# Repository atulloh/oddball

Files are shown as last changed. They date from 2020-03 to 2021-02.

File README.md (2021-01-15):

# Oddball Keyboard

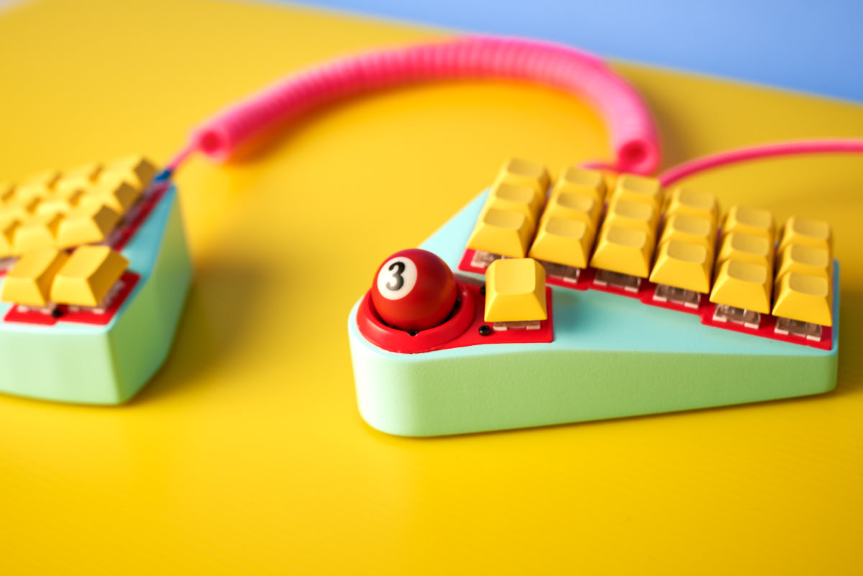
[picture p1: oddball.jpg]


The Oddball is a split mechanical keyboard with an integrated trackball. While drawing inspiration from things like the [Jian](https://github.com/KGOH/Jian-Info) and the [Dactyl Manuform](https://github.com/abstracthat/dactyl-manuform), it is instead designed with a switch plate and PCB to give it durability, replicability, and a more utilitarian look. It has a relatively minimal key layout, typically with 39 keys in total. The PCB is reversible so it can be built with 0, 1 or theoretically 2 trackballs. Due to the height and angle of the optical sensor, and as an ergonomic bonus, it requires a tented case.

- all files (cases/plates/PCBs/etc) are under [output/](https://github.com/atulloh/oddball/tree/master/output)
- all OpenSCAD files used for the 3D parts are under [src](https://github.com/atulloh/oddball/tree/master/src)

## [View the docs](https://atulloh.github.io/oddball)

## Features
- split design
- 39 keys
- trackball
- click, click + drag, scroll
- dynamic CPI (trackball cursor speed)
- columnar staggered keys
- tented case
- angled thumb clusters
- QMK firmware

Feel free to [reach out](https://atulloh.github.io/oddball/about-me) if you have any questions.

# License

MIT License

Copyright (c) 2021 Alexander Tulloh

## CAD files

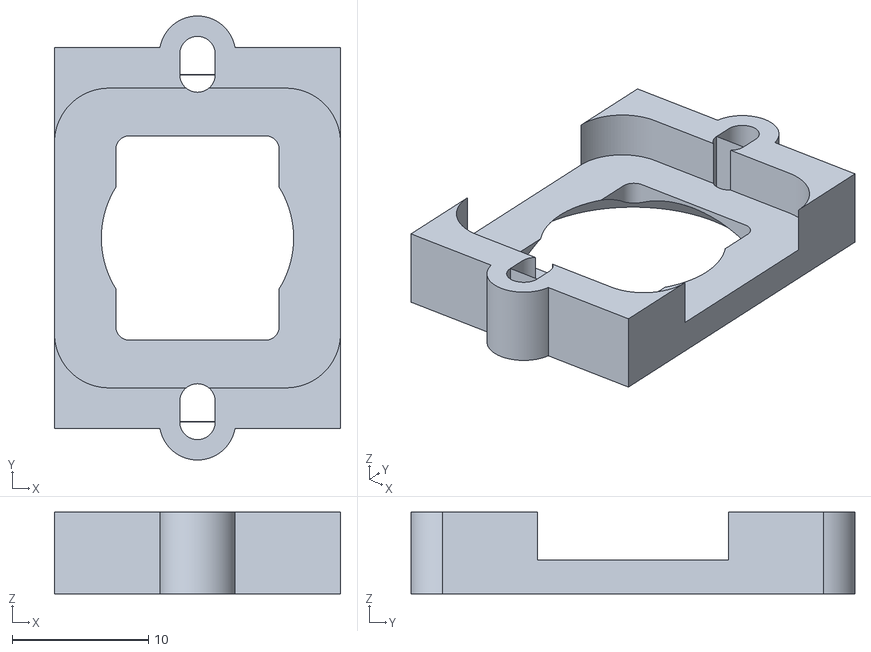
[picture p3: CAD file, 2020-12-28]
output/case/v2.0/pmwCover.stl
21.0 x 32.6 x 6.00

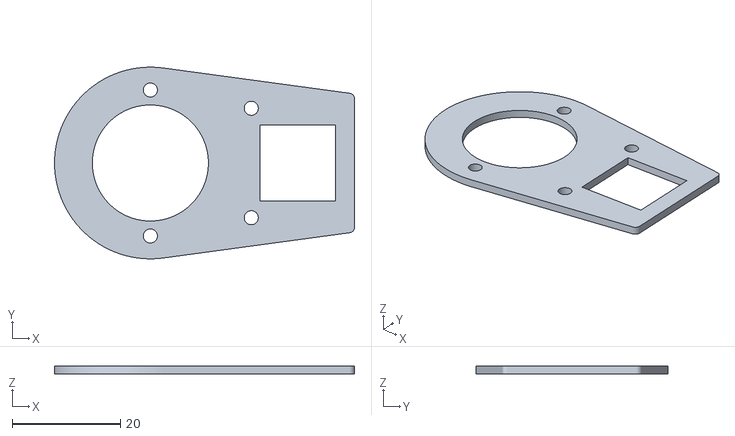
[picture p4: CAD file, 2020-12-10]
output/plates/v2.0/rightThumbPlate.stl
55.5 x 35.5 x 1.50

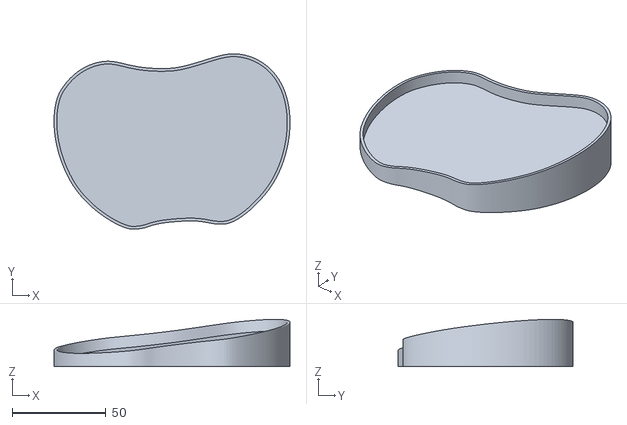
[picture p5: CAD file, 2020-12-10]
output/wristRests/leftWristRest.stl
125.7 x 93.4 x 25.2

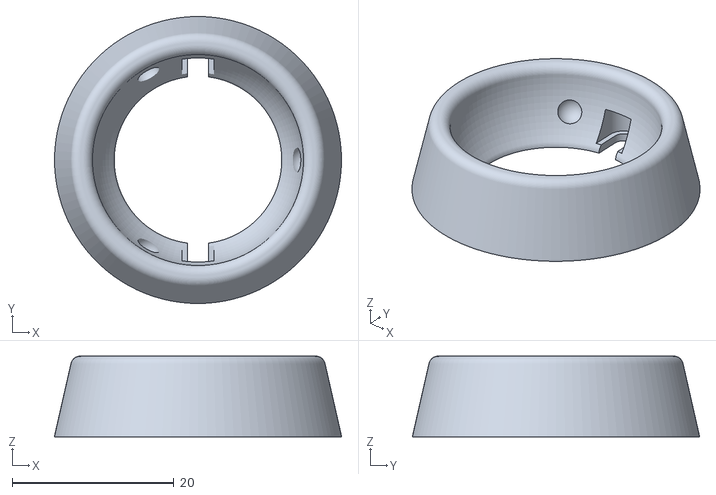
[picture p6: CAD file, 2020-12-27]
output/case/v2.0/bearingMount.stl
35.5 x 35.5 x 10.00

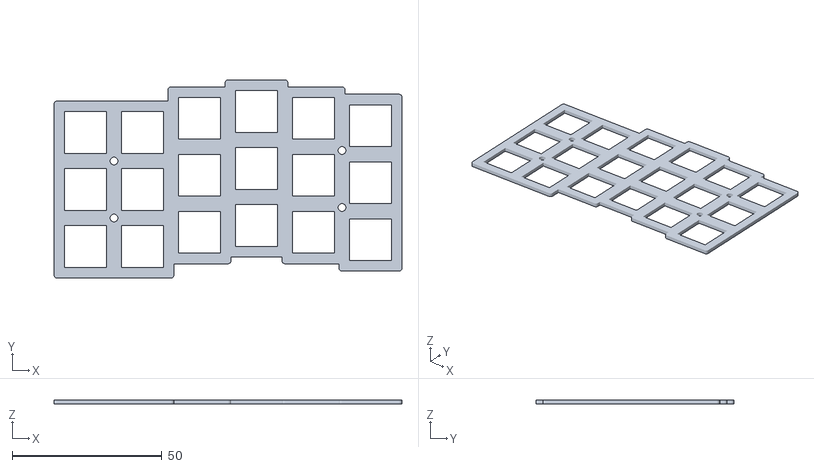
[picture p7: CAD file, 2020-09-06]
output/plates/v2.0/leftPlate.stl
116.3 x 66.2 x 1.50

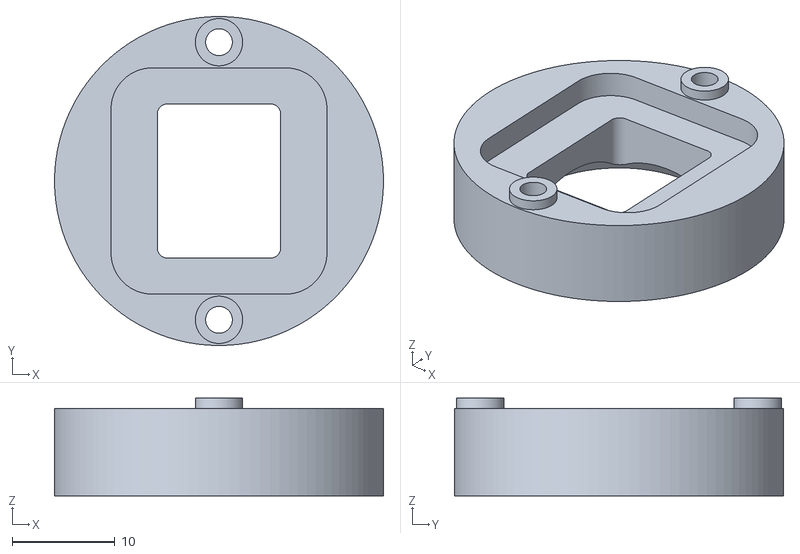
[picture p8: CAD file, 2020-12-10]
output/case/v2.0/adnsCover.stl
32.0 x 32.0 x 9.50

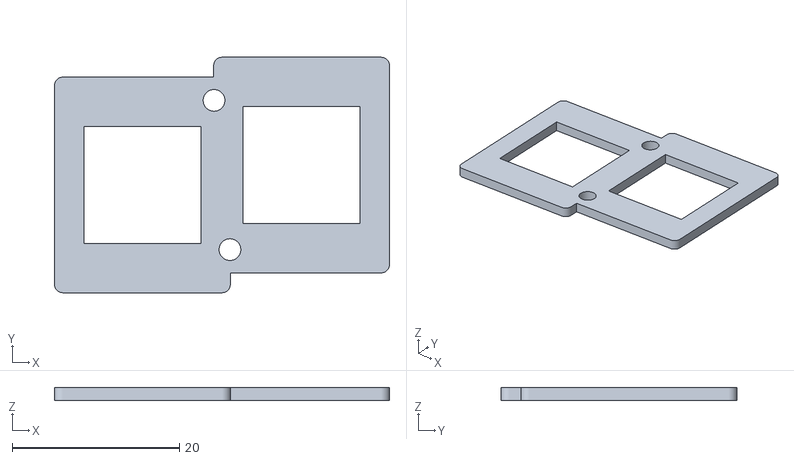
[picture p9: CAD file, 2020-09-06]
output/plates/v2.0/leftThumbPlate.stl
40.1 x 28.2 x 1.50

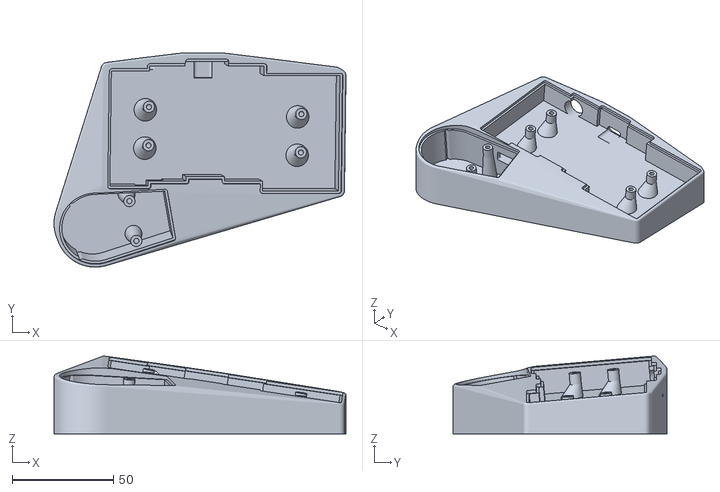
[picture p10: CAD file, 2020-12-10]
output/case/v2.0/rightCase.stl
144.3 x 105.9 x 38.4

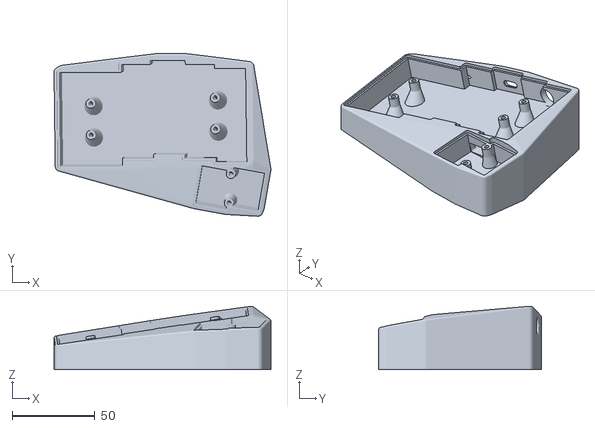
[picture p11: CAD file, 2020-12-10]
output/case/v2.0/leftCase.stl
131.4 x 98.4 x 38.4

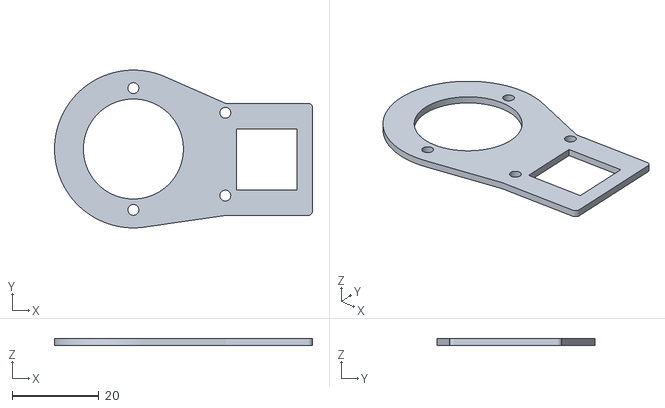
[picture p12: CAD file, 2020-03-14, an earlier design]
output/plates/v1.0/rightThumbPlate.stl
59.3 x 36.3 x 1.50

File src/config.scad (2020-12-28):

// draw flags

DRAW_DEBUG = false;

// MX constants

1U = 19.05;
SWITCH_WIDTH = 14;

// hardware

NUT_DIAMETER = 4;
NUT_HEIGHT = 3;
NUT_TOLERENCE = 0.5;
BOLT_DIAMETER = 2.4; // M2 cleanance
BOLT_TOLERENCE = 0.1;
BOLT_TOP_DIAMETER = 3.8;
BOLT_TOP_HEIGHT = 2.5;
BOLT_LENGTH = 18;
THUMB_BOLT_LENGTH = 22;

BEARING_DIAMETER = 3.175;
BEARING_TOLERENCE = 0.05;

// plate

PLATE_THICKNESS = 1.5;
PLATE_BEZEL = 1;
PLATE_CURVE_RADIUS = 1;

// trackball

TRACKBALL_BOLT_HOLES_DIAMETER = 32;
TRACKBALL_DIAMETER = 24.9;
TRACKBALL_PLATE_CLEARANCE = 1.5;
TRACKBALL_PLATE_BEZEL = 7;
TRACKBALL_BEARING_MOUNT_CLEARANCE = 1.8;
TRACKBALL_POSITION_Z = 8.35;

// common sensor

SENSOR_CHANNEL_WIDTH = 12;
SENSOR_CHANNEL_HEIGHT = 15;
SENSOR_LENS_CLEARANCE = 2.4 - 4; // 2.4 from ADNS9800/PMW3600 data sheets, but needed a slight reduction, probably due to print tolerences
SENSOR_LENS_HEIGHT_ABOVE_BOARD = 3.5;
SENSOR_LENS_WIDTH = 21; 
SENSOR_LENS_HEIGHT = 22;
SENSOR_PCB_MOUNT_OFFSET = 13.5; // distance in X/Y from centre
SENSOR_PCB_THICKNESS = 1.5;
SENSOR_PCB_UNDERSIDE_CLEARANCE = 21.5;
SENDOR_TRACKBALL_CLEARANCE = 1;

// ADNS9800 sensor

ADNS_PCB_DIAMETER = 32;

// PMW3360 sensor

PMW_PCB_WIDTH = 21;
PMW_PCB_HEIGHT = 28;
PMW_PCB_MOUNT_OFFSET = 12;

// bearing mount

BEARING_OFFSET_Z = 3.8;
BEARING_MOUNT_TOP_CURVE_RADIUS = 1.2;
BEARING_MOUNT_TOP_X_MAX = 5;
BEARING_MOUNT_HEIGHT = 10;
BEARING_MOUNT_BOLT_TOP_CLEARANCE = 1.5;
BEARING_BOLT_CLEARANCE_Z = 1;

// PCB

MX_PCB_OFFSET = 5;
PCB_CURVE_RADIUS = 2;
PCB_PLATE_OFFSET_Z = MX_PCB_OFFSET - PLATE_THICKNESS;
PCB_THICKNESS = 1.6;
PCB_UNDERSIDE_CLEARANCE = 7;
PCB_CASE_CLEARANCE = 1;
PCB_SWITCH_OFFSET = 0;

PRO_MICRO_SIZE = [17.8, 33];
PRO_MICRO_USB_OVERHANG = 2;

MCU_PCB_OFFSET = 3.5; // socket or header height
MCU_PCB_THICKNESS = 1; // Elite C

// case

CASE_PLATE_BEZEL = 1;
CASE_PLATE_TOLERENCE = 0.25;
CASE_CURVE_RADIUS = 1;
CASE_PLATE_MOUNT_COVERAGE = 1;
CASE_BOLT_HOUSING_WIDTH = 1.5;
CASE_BOTTOM_THICKNESS = 2;
CASE_HEIGHT_ABOVE_PLATE = 0;
CASE_STANDOFF_FLANGED = true;

// case feet cutouts

FEET_DIAMETER = 8;
FEET_TOLERENCE = 1.25;
FEET_HEIGHT = 1;

// layouts in 1U space

FINGER_GRID = 
    [[0, 2], [1, 2], [2, 2.25], [3, 2.37], [4, 2.25], [5, 2.12],
     [0, 1], [1, 1], [2, 1.25], [3, 1.37], [4, 1.25], [5, 1.12],
     [0, 0], [1, 0], [2, 0.25], [3, 0.37], [4, 0.25], [5, 0.12]];

FINGER_BOLT_HOLES =
    [[1, 2], [5, 2.185],
     [1, 1], [5, 1.185]];

THUMB_GRID = [[0, 0], [1, 0.1]];

THUMB_BOLT_HOLES = 
    [[0.95, 0.925],
     [1.05, 0.175]];

THUMB_TRACKBALL_GRID = [[0, 0], [1.43, 0, "pmw" /* "adns" */ ]];

THUMB_TRACKBALL_BOLT_HOLES = 
    [[0.95, 0.925],
     [0.95, 0.075]];

FEET_POSITIONS =
    [[0.3, 2.75], [5.6, 2.85],
     [0.3, 0.3], [5.95, -1.1]];

THUMB_FEET_POSITIONS =
    [[0.3, 2.75], [5.6, 2.85],
     [0.3, 0.3], [6.45, -1.25]];

// plane rotations

HAND_ROTATION = [5, -8.5, 0];
THUMB_ROTATION = [10, -2, -10.25];
THUMB_OFFSET = [80.5, -22, 8.5];

// cutouts

USB_C_SIZE = [8.98, 9.20, 3.28];
USB_C_CUTOUT_TOLERENCE = 0.5;
USB_C_CUTOUT_OUTER_DELTA = 1.5;

TRRS_CUTOUT_SIZE = 5.5;
TRRS_CUTOUT_OUTER_DELTA = 5.5;

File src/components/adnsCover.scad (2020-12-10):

use<../modules/adnsCover.scad>;

// flip; easier to 3D print
rotate([180,0,0])
    adnsCover($fn = 100);

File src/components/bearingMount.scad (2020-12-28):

include<../config.scad>;
use<../modules/plate.scad>;
use<../modules/bearingMount.scad>;

bearingMount($fn = 100);

if(DRAW_DEBUG)
    %translate([0,0,TRACKBALL_POSITION_Z])
        sphere(d = TRACKBALL_DIAMETER);

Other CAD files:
output/plates/v1.0/leftThumbPlate.stl
output/plates/v1.0/leftPlate.stl
src/components/handPcb.scad
output/plates/v1.0/leftPlate.dxf
output/plates/v1.0/leftThumbPlate.dxf
output/plates/v1.0/rightThumbPlate.dxf
output/plates/v2.0/leftPlate.dxf
output/plates/v2.0/leftThumbPlate.dxf
output/plates/v2.0/rightThumbPlate.dxf
src/components/leftCase.scad
src/components/leftPlate.scad
src/components/leftThumbPlate.scad
src/components/pmwCover.scad
src/components/rightCase.scad
src/components/rightPlate.scad
src/components/rightThumbPlate.scad
src/components/thumbPcb.scad
src/modules/adnsCover.scad
src/modules/bearingMount.scad
src/modules/case.scad
src/modules/keycap.scad
src/modules/keys.scad
src/modules/leftCase.scad
src/modules/pcb.scad
src/modules/plate.scad
src/modules/pmwCover.scad
src/modules/rightCase.scad
src/modules/shapes.scad
src/modules/switch.scad
src/tests/leftCaseCutouts.scad
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

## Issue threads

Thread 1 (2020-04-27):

Add plate source

atulloh, 2020-04-27:

atulloh, 2020-05-04:
This is basically covered in https://github.com/atulloh/oddball/pull/4

The goal was to take out all the hacky tweaks that were happening with the initial OpenSCAD code, and pull out all parameters into a single file.

I've added the scad files and also the output STL and DXF files for the plates and bearing mount.

Closed 2020-05-04.

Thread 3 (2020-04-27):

Create build guide

atulloh, 2020-04-27:

jdayton3, 2020-04-27:
@atulloh - if you have an extra set of PCBs you'd like to sell and would like someone to help with the build guide or be a beta tester or anything like that, feel free to hit me up! You can PM me at u/knot-a-robot, respond here, or find my other contact info at my GitHub profile -> home page if you're interested. I'm super excited about this project!

atulloh, 2020-04-27:
Thanks @jdayton3 , I'll definitely need feedback on the build process; I'll keep you posted.

keyboard-magpie, 2020-10-10:
hey @atulloh just ordered some v2 pcbs; does the build guide need an update to mention these? I saw the silks changed from teensy to elite c.

atulloh, 2020-10-11:
Hey @keyboard-magpie ...

> hey @atulloh just ordered some v2 pcbs...

Wow, you're on ball! I've only just ordered some too, you might even beat me to it.

> ...does the build guide need an update to mention these? I saw the silks changed from teensy to elite c.

Yep. I never actually wrote a build guide for v1 (sorry @jdayton3 !). I'm just in the process of doing it for both v1/v2 on this work-in-progress branch: https://github.com/atulloh/oddball/tree/blog/v2. The formatting and images won't actually work correctly until it's merged into the GitHub pages branch as it's generated with Jekyll. I also probably won't merge it in until I've actually finished a build, which will be several weeks as I'm still waiting for parts to arrive.

The main changes for v2 were:
- switched to Elite C
- added support for PMW3360 (although you can still use an ADNS9800)

I'll update this issue when I get around to merging the build guide in.

keyboard-magpie, 2020-10-14:
I should ask, are there any case differences between v1 and 2?

atulloh, 2020-10-14:
Yep, slight changes, mainly to:
- make assembly easier
- make room for the PMW3360

You can see the work-in-progress files here: https://github.com/atulloh/oddball/blob/develop/v2.0/output/case/v2.0/

Hopefully I can get my printer back in the next week or two (we are under lockdown due to virus), then do some test prints, make some measurements, and get the case files finished up.

atulloh, 2020-10-14:
@keyboard-magpie nice! Like I said though, the cases are a work-in-progress; I'll need to tweak the cable cutouts. I'll probably also try to reduce the height a bit. I'll merge that `develop/v2.0` branch back into `master` when I've had a chance that every fits together okay.

Sure, discord is tullonator#6580

gorbachev, 2021-01-04:
I just finished printing the cases...doing a test run with 3D printed plates before shelling out the money for plates with more expensive materials. Case design looks simple enough to figure out without a build guide. I'm familiar with Kicad, so the connections to the thumb PCBs / trackball controller looks pretty intuitive. The spacers / screw sizing will be a bit of experimentation I guess. Not quite there yet.

BTW, kudos on the case design. It prints really easily. Assembly is also really simple.

I could use a bit of help with the actual trackball, however. The only place I could find any information about it was your Reddit post on /r/mk. So you're using a mini pool ball and ceramic balls embedded into the mount.

What size is that mini pool ball? Last time I looked on eBay there were a few different sizes and I couldn't figure out which size is the right one. 1.5" seemed to be the most common size, but there are sizes ranging from 1" to 2".

Also where would I go and buy the small ceramic balls, and what size are they?

gorbachev, 2021-01-04:
This is great! Thank you!

atulloh, 2021-01-06:
> * M2 nuts x12

Sorry, I meant x14.

atulloh, 2021-01-15:
This has been merged in. If anyone has any feedback or wants changes, I think you can open an issue in GitHub.

@gorbachev if you get around to making a build, I've added a section where people can add photos of their Oddball builds https://atulloh.github.io/oddball/community-builds.html

It's a tricky build, so I doubt there will be many, but prove me wrong 😛

atulloh, 2021-01-15:
See previous comment.

atulloh, 2021-01-15:
Oh, and for the record, the build guide is: https://atulloh.github.io/oddball/v2/build-guide.html

Closed 2021-01-15.

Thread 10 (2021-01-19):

Bug in USB Cutout position

Aapjes94, 2021-01-19:
Hi,

Thanks for the in-depth guide. I'm preparing for a build with an extra row, as I really need a number row. While adding the finger positions and moving the cut-outs for the cables I think I found a bug.

The right case half didn't match the left one and in modules/rightCase.scad on line 38 I found
`PCB_UNDERSIDE_CLEARANCE - MCU_PCB_OFFSET - MCU_PCB_THICKNESS - USB_C_SIZE.z / 2 + 5],`

The corresponding line for the left case seems to be the correct one.
`PCB_UNDERSIDE_CLEARANCE - max(MCU_PCB_OFFSET, USB_C_SIZE.z) + USB_C_SIZE.z / 2]`

atulloh, 2021-01-19:
Thanks @Aapjes94 ; I'll have a look. That `+5` looks a bit weird, but I was tweaking those cutouts towards the end, so I probably hacked it a little.

One thing to note is that when using a PCB and Elite-C/Pro Micro, when switching sides, the USB port flips direction. e.g.
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

If you are adding an extra row, are you planning to hand wire? If so, it's not as much as an issue, you can probably put the cutouts wherever you want really.

Aapjes94, 2021-01-20:
Thanks for pointing out the USB positions, hadn't thought about that yet. I thought that the point of the Elite-C/ProMicro was that the USB port was centered on the microcontroller, but it seems to be ever so slightly (0.8 mm) offset. With a small spacer on the left side, it should be possible to get the USB at a constant distance from the PCB.
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

I have never designed a PCB before so would really like to go that way, however, I'll have to figure out how hard that is going to be on the way. I'll probably give it a go and if the PCB fails, I'll go with handwriting. If this all ends up working I'll share the files with you.

atulloh, 2021-01-20:
Oh ok. Yes I used an v3.1 Elite-C, and it wasn't quite the same offsets. I'll update the case code accordingly.

atulloh, 2021-01-20:
I've added some new code and named case files on a fix branch, here:

https://github.com/atulloh/oddball/tree/fix/10-elite-c-cutout/output/case/v2.0

I've linked these with a little explanation in the build guide's *Bill of Materials* under the case/MCU sections.

When I get around to ordering a v4 Elite-C, or hear back from someone that the new case files worked, I'll merge this in and close.

atulloh, 2021-02-02:
> When I get around to ordering a v4 Elite-C, or hear back from someone that the new case files worked, I'll merge this in and close.

Ordered! I should have one to test out in the next week or so.

Aapjes94, 2021-02-03:
I hope you don't mind it's a bit off-topic, but tangentially related to an earlier comment. Would you be comfortable sharing the file you used to create the PCB files? I think I'd like to take a crack at using a PCB instead of hand wiring this thing with the extra row.

atulloh, 2021-02-04:
> I hope you don't mind it's a bit off-topic, but tangentially related to an earlier comment. Would you be comfortable sharing the file you used to create the PCB files? I think I'd like to take a crack at using a PCB instead of hand wiring this thing with the extra row.

Sure. I wasn't planning to open sourcing it; I might go down the track of trying to improve it and make some for sale. To be honest, this was my first PCB and isn't the best, and breaks some basic design principles. I can send you the project; add me on Discord (tullonator#6580) or send me at email to alexandertulloh at gmail dot com and I'll get back to you.

pannet1, 2023-09-09:
when is this going to be available for sale

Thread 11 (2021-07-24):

Missing .scad for wrist rest bases?

OJFord, 2021-07-24:
I noticed you have very similar wrist rests to the one I ordered, but on a 3D printed angled base. I do see that the STL is in `output` dir, but there doesn't seem to be any corresponding source?

The one I ordered looks to be the same shape, but it is just black and doesn't say 'microban', so it'd be good to be able to double-check dimensions before printing just in case.

Thanks.

atulloh, 2021-07-27:
Oh, sorry, took a while to see this notification.

Sure, I'll try dig up the source if I can find it.

OJFord, 2021-07-28:
No worries, thanks!

atulloh, 2021-08-03:
[wrist_rests.zip](https://github.com/atulloh/oddball/files/6924228/wrist_rests.zip)

Found the files. was from an older repo. The config is a little different to this repo, but all the files in the zip should work together. The SVG is just an image I traced while holding my wrist rest against my PC screen, so it isn't 100 accurate, then I applied some weird scaling in the SCAD file to get it to fit just right. Was good enough for my purposes.

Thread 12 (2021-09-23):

Standard/easier to find m2 screw lengths?

alairock, 2021-09-23:
This isn't really an issue with the design so much as it is a sourcing issue. The screw lengths are 18 and 22, which are both really tough to find.

It would be really awesome if we could get those down to 16mm or shorter. I can find 16mm m2 screws much much easier. Otherwise I have to order them on alibaba and it takes weeks/months to arrive.

alairock, 2021-10-04:
Modified the file for the shorter screws. Worked great! Excellent variable design!

atulloh, 2021-10-04:
Hey @alairock , sorry, missed the notification for this. Glad you got it sorted out 😄

If I ever get around to a redesign, I'll probably switch them for threaded inserts; much less fiddly!

Closed 2021-10-04.

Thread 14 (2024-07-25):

PCB related files

inverseTrig, 2024-07-25:
Hi, I love what you have created here, but I want to add one extra thumb keys on each side. Thankfully the comments in the configs made it easy to modify the SCAD files but there are no files related to the PCB to be found.

Would you mind adding the PCB related files (KiCad?) to the repository?

piit79, 2024-10-25:
I was also surprised that the PCB does not seem to be open-source... Is that intentional? I'd love to tinker with the (hopefully) KiCad sources. Would you be so kind to upload them? Thanks!

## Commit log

2020-03-14 Add public files
    [hand.dxf, thumb-and-ball.dxf, thumb.dxf]
2020-03-14 Add stl files
    [hand.stl, thumb-and-ball.dxf, thumb.stl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]
2020-08-26 Develop/v1.1 (#6)
    * Develop/gh 1 (#4)
    * Inital commit of plates source
    * Add debug drawing of swtiches/keys
    * Move bolt positions to 1U spave
    * Add bearing mount
    * Add debug keys to all plates and parameterise bearing mount
    * Restructued scad directories
    * Updated files to use same naming convention
    * Rework directory structure and add new plate stl/dxf files
    * Gh 2 (#5)
    * Initial commit of case
    * Parameterise case into sections
    * Add case files
    * Initial commit of cutouts
    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
    [bearingMount.scad, case.scad, config.scad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]
2020-08-31 Improve output directory structure
    [leftPlate.dxf, leftPlate.stl, leftThumbPlate.dxf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]
2020-09-02 Add variable base thickness per section
    [case.scad, config.scad, leftCase.scad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]
2020-09-02 Increase right case resolution
    [rightCase.scad]
2020-09-02 Fix issues with standoff heights based on base thickness
    [case.scad]
2020-09-03 Parameterise feet positions
    [case.scad, config.scad, leftCase.scad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]
2020-09-05 Add variable bolt lengths
    [case.scad, config.scad, leftCase.scad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]
2020-09-05 Add test prints
    [adns.scad, cutouts.scad]
2020-09-06 Fix bug in plate scale
    [plate.scad]
2020-09-06 Improve left thumb plate screw alignment
    [config.scad]
2020-09-06 Update plate exports
    [leftPlate.dxf, leftPlate.stl, leftThumbPlate.dxf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]
2020-09-06 Revert case resolution
    [leftCase.scad]
2020-09-07 Add ADNS cover
    [adnsCover.scad, config.scad, keys.scad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]
2020-09-10 Initial commit of PMW integration
    [bearingMount.scad, config.scad, keys.scad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]
2020-09-10 Improve ball position and pmw cover
    [config.scad, pmwCover.scad]
2020-09-20 Add v1 and v1.1 gerbers
    [oddball-B_Cu.gbr, oddball-B_Mask.gbr, oddball-B_SilkS.gbr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]
2020-09-20 Fix resolution
    [rightCase.scad]
2020-09-22 Improve cutout for USB-C cable
    [case.scad, config.scad]
2020-09-24 Fix odd value in plate bezel around trackball
    [bearingMount.scad, config.scad, plate.scad]
2020-09-24 Add cutout for PMW in case
    [case.scad]
2020-09-24 Fix pmw cover hole alignments
    [pmwCover.scad]
2020-09-24 Initial commit of PCB borders
    [handPcb.scad, pcb.scad, thumbPcb.scad]
2020-09-25 Increase trackball plate bolt ball clearance
    [config.scad]
2020-09-30 Move outputs to type folders
    [leftPlate.dxf, leftPlate.stl, leftThumbPlate.dxf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]
2020-12-10 Develop/v2.0 (#7)
    * Initial commit of v2 case files
    * Invert sensor for easier printing
    * Reduce clearance on sensor covers
    * Move scad files up one level and remove functions from components
    * Initial commit of wrist rest
    * Add explicit bearing mount component
    * Move wrist rest to own folder
    * Move reset channel
    * Parameterise feet, TRRS and USB cutout positions
    * Add script to build all components
    * Move reset button channel up
    * Add case sides as modules
    * Update test prints to use common module code
    * Tweak TRRS cutouts
    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
    [adns.scad, adnsCover.scad, adnsCover.stl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]
2020-12-10 Rebuild bearing mount output
2020-12-11 Fix issue where right thumb cutout using incorrect variable for depth
    [config.scad, rightCase.scad]
2020-12-18 Develop/bearing mount (#8)
    * Test different bearing fixture
    * Move bearing up
    * Update bearing mount output
    * Increase bearing tolerance
    * Reduce bearing cutout
    * Rework mount to not need supports
    [bearingMount.scad, config.scad]
2020-12-27 Increase bearing mount bolt access
    [bearingMount.scad, bearingMount.stl, config.scad]
2020-12-27 Reduce sensor lens clearance
    [adnsCover.scad, config.scad, pmwCover.scad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]
2020-12-28 Change to define trackball position rather than standoff height
    [adnsCover.scad, bearingMount.scad, config.scad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]
